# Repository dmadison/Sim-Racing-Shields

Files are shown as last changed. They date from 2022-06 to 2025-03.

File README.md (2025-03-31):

# Sim Racing Shields for Arduino

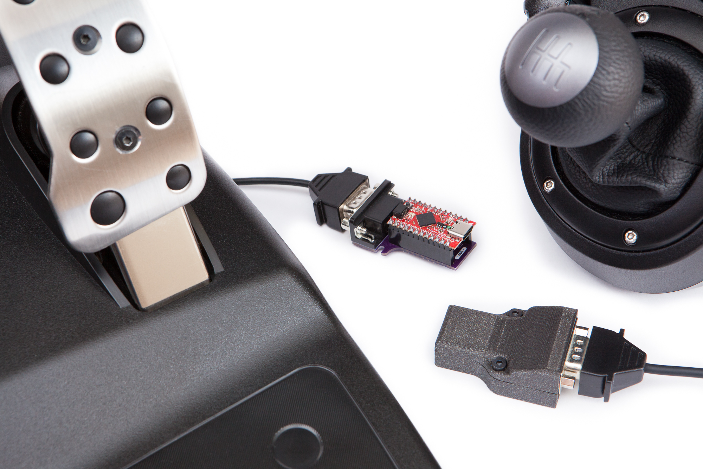
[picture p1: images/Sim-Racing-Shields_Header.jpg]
Sim Racing Shields Header


This repo contains add-on circuit boards ("shields") for connecting Arduino development boards to sim racing equipment. These shields are meant to be used in conjunction with the [Sim Racing Library for Arduino](https://github.com/dmadison/Sim-Racing-Arduino). These shields can be used to create inexpensive, standalone USB HID adapters for use with racing games and simulators.

Both of these shields are designed to be used with a [SparkFun Pro Micro, 5V (32U4)](https://github.com/sparkfun/Pro_Micro). You can use either genuine SparkFun boards or 3rd party clones. The [SparkFun Qwiic Pro Micro with a USB-C port (DEV-15795)](https://www.sparkfun.com/products/15795) is recommended. The SparkFun Pro Micro RP2040 is theoretically compatible but has not been tested. Note that the Tag-Connect programming header is not compatible with the RP2040.

The shields can be assembled with either 0.1″ female headers for prototyping or 0.1″ male headers for a permanent connection. Only assembled boards with male headers will be able to fit inside the 3D printed case.

For more information, [see the article on PartsNotIncluded.com](https://www.partsnotincluded.com/sim-racing-shields-for-arduino/).

## Logitech Shifter Shield for Pro Micro

The [Logitech Shifter Shield](pcbs/Logitech_Shifter_Shield_Pro_Micro) is designed to interface with all available Logitech shifters using a single DB-9 male connector:
* [Logitech Driving Force shifter (G923 / G920 / G29)](https://www.logitechg.com/en-us/products/driving/driving-force-shifter.html)
* [Logitech G27 shifter](https://en.wikipedia.org/wiki/Logitech_G27)
* [Logitech G25 shifter](https://en.wikipedia.org/wiki/Logitech_G25)

This repo includes firmware ([LogitechShifterShield](firmware/LogitechShifterShield/LogitechShifterShield.ino)) which works out of the box as a USB HID adapter for all three shifter types.

You can also write your own firmware using the [Sim Racing Library for Arduino](https://github.com/dmadison/Sim-Racing-Arduino). Use the `SimRacing::CreateShieldObject()` template function for easy setup with the shifter shield:

```cpp
LogitechShifterG29 shifter = SimRacing::CreateShieldObject<SimRacing::LogitechShifterG29, 2>();
LogitechShifterG27 shifter = SimRacing::CreateShieldObject<SimRacing::LogitechShifterG27, 2>();
LogitechShifterG25 shifter = SimRacing::CreateShieldObject<SimRacing::LogitechShifterG25, 2>();
```

## Logitech Pedal Shield for Pro Micro

The [Logitech Pedal Shield](pcbs/Logitech_Pedal_Shield_Pro_Micro) is designed to interface with the Logitech three pedal attachment, included with the Logitech G923 “TRUEFORCE”, G29/G920 “Driving Force”, and G27/G25 wheels, via a single DB-9 female connector.

This repo includes firmware ([LogitechPedalShield](firmware/LogitechPedalShield/LogitechPedalShield.ino)) which works out of the box as a USB HID adapter for the pedals.

You can also write your own firmware using the [Sim Racing Library for Arduino](https://github.com/dmadison/Sim-Racing-Arduino). Use the `SimRacing::CreateShieldObject()` template function for easy setup with the pedals shield:

```cpp
LogitechPedals pedals = SimRacing::CreateShieldObject<SimRacing::LogitechPedals, 2>();
```

## Firmware

The shields are designed to be used with the [Sim Racing Library for Arduino](https://github.com/dmadison/Sim-Racing-Arduino). You can use any included example for your specific hardware, or write your own using the data the library provides.

Both shields use the SparkFun Pro Micro (32U4), and firmware should be compiled using the "SparkFun Pro Micro" board in the Arduino IDE. You can find the compilation files and installation instructions for the Pro Micro [here](https://github.com/sparkfun/Arduino_Boards). You do not need to install the SparkFun boards package if you are using the custom boards package below.

### Custom Boards Installation

To install the custom boards package, start up the Arduino IDE and open the preferences window (**File > Preferences**). Copy and paste this URL for the package index into the "Additional Boards Manager URLs" field:

```
https://github.com/dmadison/Sim-Racing-Shields/raw/master/arduino-boards/boards-manager/package_simracing_index.json
```

In the menu, navigate to **Tools > Board > Boards Manager** and open up the boards manager. Search for "Sim Racing" and then install the "Sim Racing AVR Boards" package. After the package is installed you should be able to select the "SparkFun Pro Micro (for Sim Racing)" board.

### Custom Boards Configuration

The custom boards package adds two new options to the boards menu:

* USB Identity
* Serial Port

The first option, 'USB Identity', changes the USB PID and USB description for the board. Firmware compiled with the 'Shifter' option will present as "Sim Racing Shifter" with a PID of 0x9101, while firmware compiled with the 'Pedals' option will present as "Sim Racing Pedals" with a PID of 0x9102.

The second option, 'Serial Port', allows you to disable the USB CDC serial port. This improves compatibility with some systems and prevents accidentally reprogramming the board. Note that if you remove the USB CDC serial port the board will no longer automatically reset to the bootloader during programming. You will have to reset the board yourself or use an external programmer.

## Case

[A 3D printed case design](cad) is available to protect the assembled shield and microcontroller. Both shields share the same general footprint and the same case design. When assembled, the case should hold the microcontroller and shield securely without any play.

The case is printed in two parts, and assembled using two M3-10 bolts and two M3 nuts. The recommended print orientation is as-is. Note that the top half of the case is a little tricky to print, and must be printed using bed supports.

## Building Your Own

If you'd like to make these yourself, you can find the [Gerber files](https://en.wikipedia.org/wiki/Gerber_format) and [Bill of Materials (BOM)](https://en.wikipedia.org/wiki/Bill_of_materials) in [the latest release](https://github.com/dmadison/Sim-Racing-Shields/releases/latest).

## License

The files in this repository are licensed under the terms of the [GNU General Public License (GPL)](https://www.gnu.org/licenses/gpl-3.0.html), either version 3 of the License, or (at your option) any later version. See the [LICENSE](LICENSE) file for more information.

Included images are licensed under the [CC BY-NC-ND 4.0 license](https://creativecommons.org/licenses/by-nc-nd/4.0/). Attribution should be to Dave Madison ([@dmadison](https://github.com/dmadison)).

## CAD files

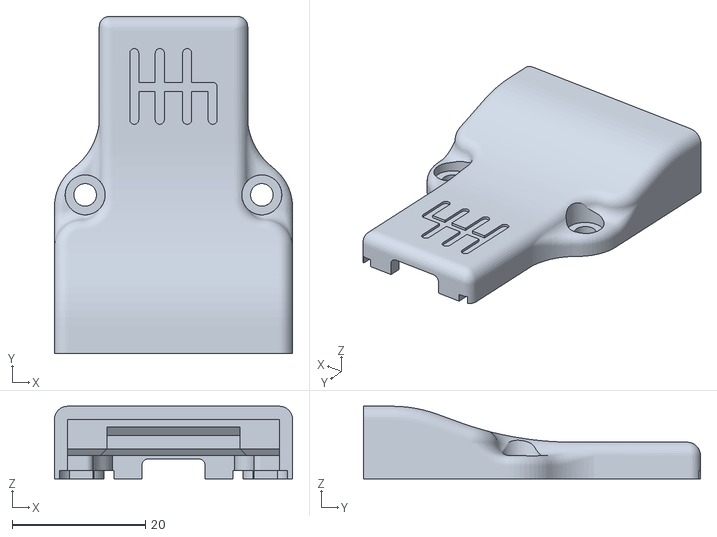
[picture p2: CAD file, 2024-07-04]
cad/Logitech Sim Racing Adapter Case - Top (Shifter).stl
35.7 x 50.6 x 10.9

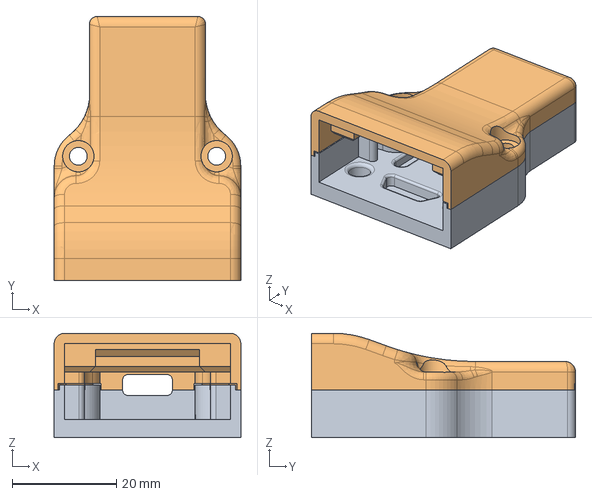
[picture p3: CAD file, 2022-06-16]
cad/Logitech Sim Racing Adapter Case.step
35.7 x 50.6 x 20.0 mm

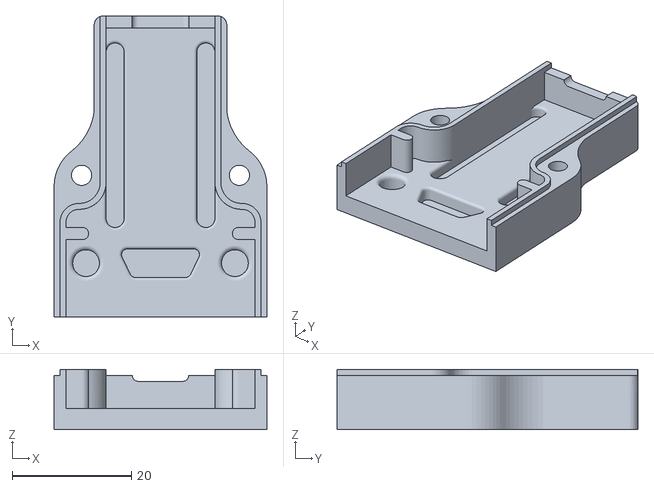
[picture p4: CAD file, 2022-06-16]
cad/Logitech Sim Racing Adapter Case - Bottom.stl
35.7 x 50.6 x 10.1

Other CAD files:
cad/Logitech Sim Racing Adapter Case - Top (Pedals).stl
cad/Logitech Sim Racing Adapter Case - Top.stl
cad/Logitech Sim Racing Adapter Case.f3d

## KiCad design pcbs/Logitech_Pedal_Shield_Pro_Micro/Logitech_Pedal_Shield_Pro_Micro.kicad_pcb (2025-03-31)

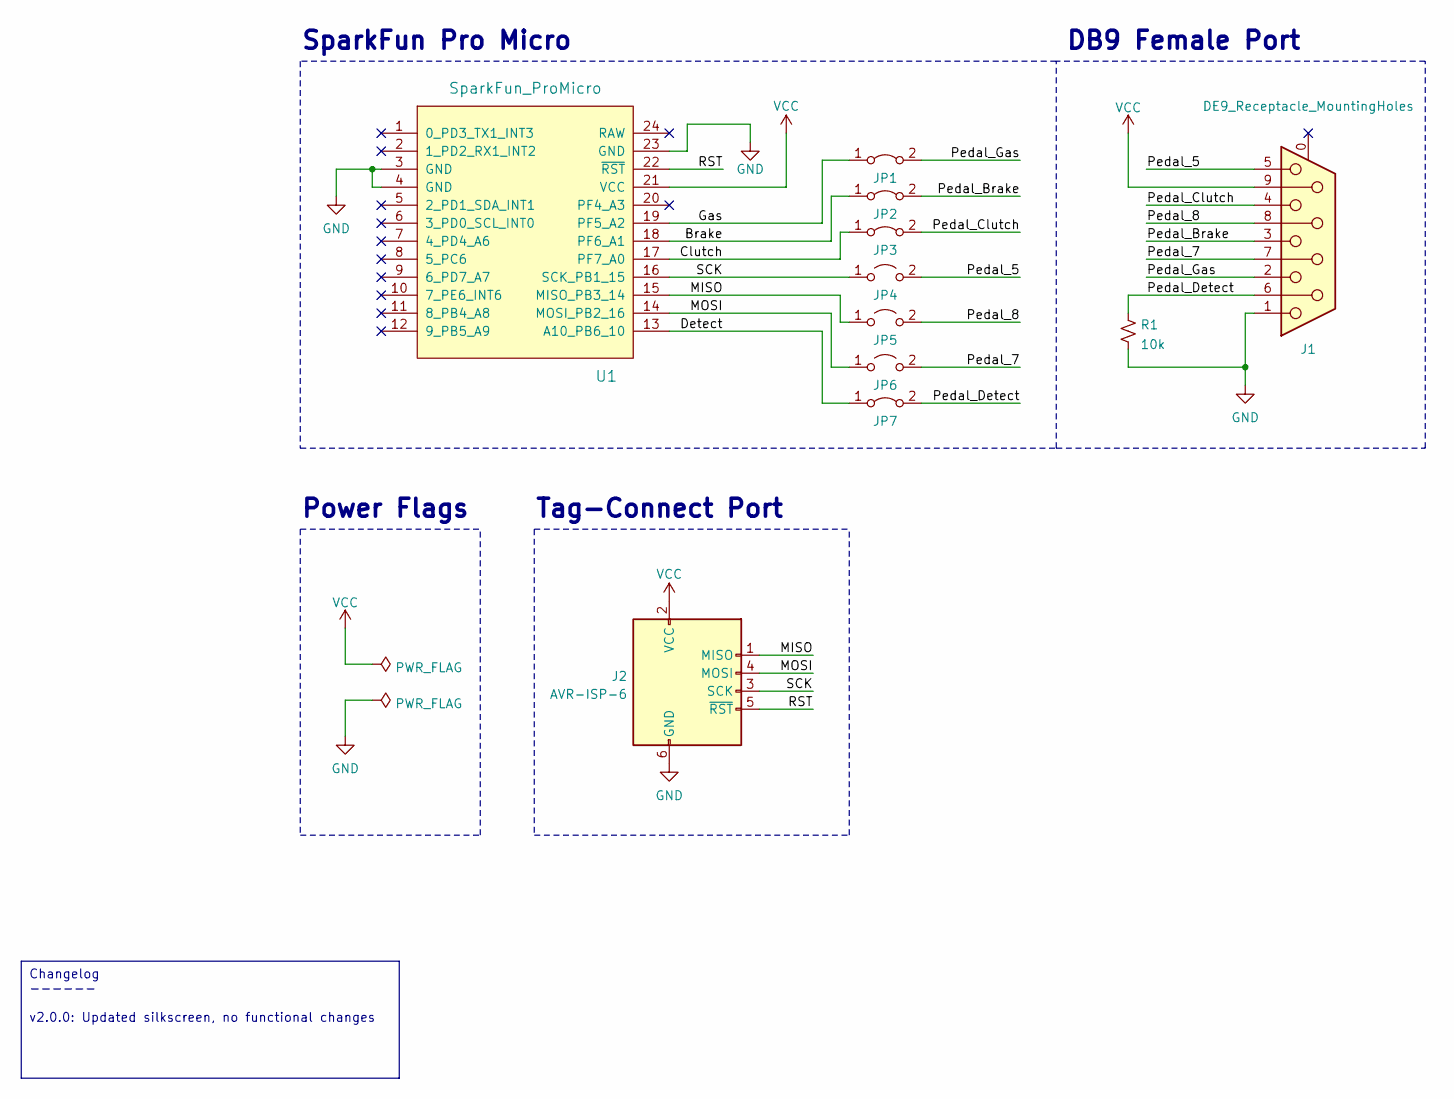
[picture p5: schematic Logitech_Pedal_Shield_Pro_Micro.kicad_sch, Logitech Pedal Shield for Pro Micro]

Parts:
J1: DE9_Receptacle_MountingHoles; DSUB-9_Female_Horizontal_P2.77x2.84mm_EdgePinOffset7.70mm_H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; Part Number A-DF 09 A/KG-T2S; DigiKey Part Number AE10921-ND
J2: AVR-ISP-6; Tag-Connect_TC2030-IDC-NL_2x03_P1.27mm_Vertical
JP1: Gas_Jumper; SolderJumper-2_P1.3mm_Bridged_RoundedPad1.0x1.5mm_Unmasked
JP2: Brake_Jumper; SolderJumper-2_P1.3mm_Bridged_RoundedPad1.0x1.5mm_Unmasked
JP3: Clutch_Jumper; SolderJumper-2_P1.3mm_Bridged_RoundedPad1.0x1.5mm_Unmasked
JP4, JP5, JP6: Jumper_2_Open; SolderJumper-2_P1.3mm_Open_RoundedPad1.0x1.5mm
JP7: Detect_Jumper; SolderJumper-2_P1.3mm_Bridged_RoundedPad1.0x1.5mm_Unmasked
R1: 10k; R_0805_2012Metric; Part Number RC0805FR-0710KP; DigiKey Part Number YAG1319CT-ND
U1: SparkFun_ProMicro; Sparkfun_ProMicro; Part Number DEV-15795; DigiKey Part Number 1568-DEV-15795-ND

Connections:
/Brake: JP2.1 (A), U1.18 (PF6_A1)
/Clutch: JP3.1 (A), U1.17 (PF7_A0)
/Detect: JP7.1 (A), U1.13 (A10_PB6_10)
/Gas: JP1.1 (A), U1.19 (PF5_A2)
/MISO: J2.1 (MISO), JP5.1 (A), U1.15 (MISO_PB3_14)
/MOSI: J2.4 (MOSI), JP6.1 (A), U1.14 (MOSI_PB2_16)
/Pedal_5: J1.5, JP4.2 (B)
/Pedal_7: J1.7, JP6.2 (B)
/Pedal_8: J1.8, JP5.2 (B)
/Pedal_Brake: J1.3, JP2.2 (B)
/Pedal_Clutch: J1.4, JP3.2 (B)
/Pedal_Detect: J1.6, JP7.2 (B), R1.2
/Pedal_Gas: J1.2, JP1.2 (B)
/RST: J2.5 (~RST), U1.22 (~RST)
/SCK: J2.3 (SCK), JP4.1 (A), U1.16 (SCK_PB1_15)
GND: J1.1, J2.6 (GND), R1.1, U1.3 (GND), U1.4 (GND), U1.23 (GND)
VCC: J1.9, J2.2 (VCC), U1.21 (VCC)

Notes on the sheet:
Changelog ------ v2.0.0: Updated silkscreen, no functional changes
Tag-Connect Port
Power Flags
DB9 Female Port
SparkFun Pro Micro

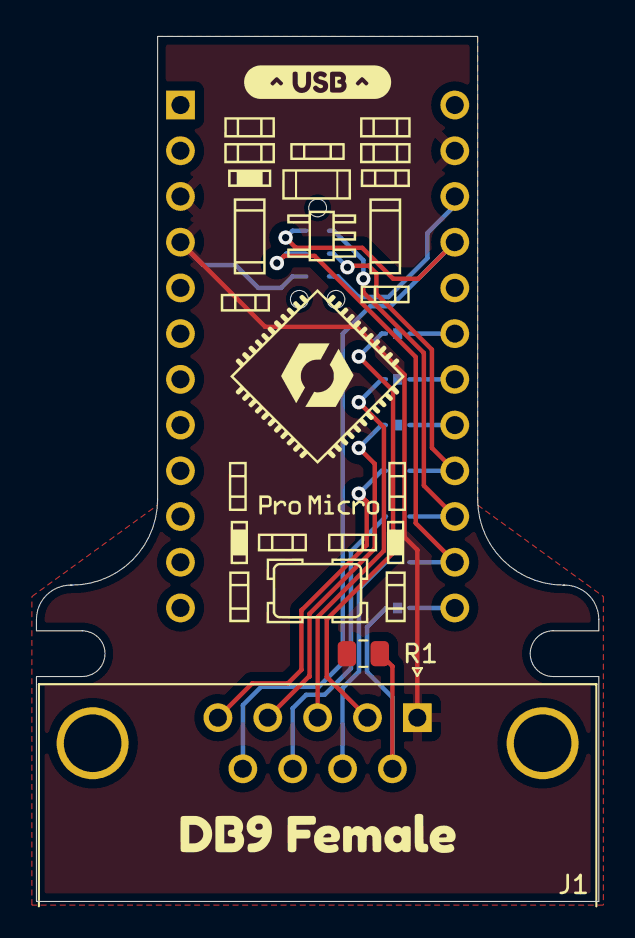
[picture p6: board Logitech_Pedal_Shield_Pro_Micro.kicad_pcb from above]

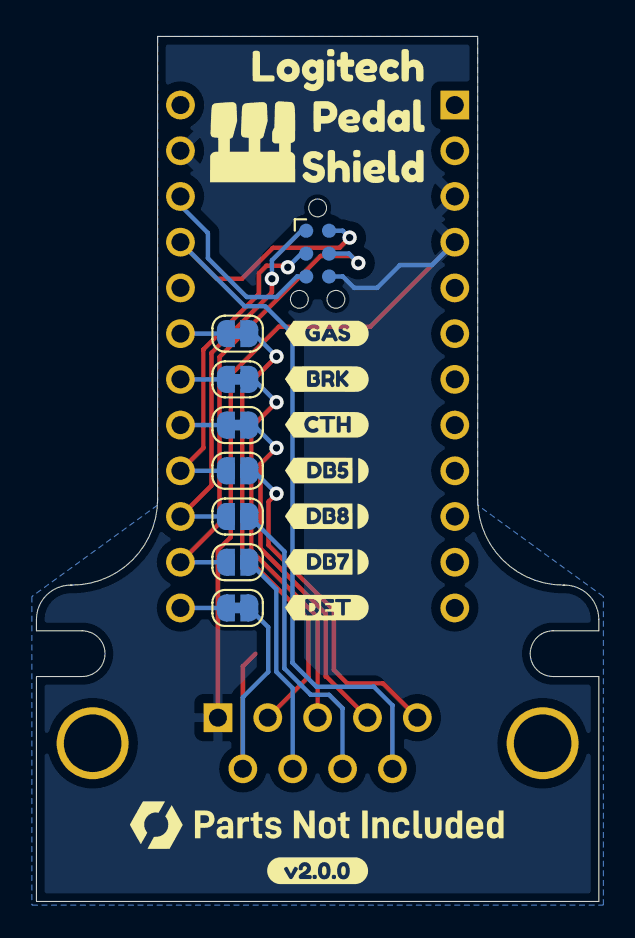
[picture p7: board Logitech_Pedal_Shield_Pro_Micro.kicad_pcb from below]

Board: 2 copper layers, 31.2 x 48.1 mm, 12 parts (8 on the bottom side), 17 nets.

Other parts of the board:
kibuzzard-61EDBB73: G***; kibuzzard-61EDBB73

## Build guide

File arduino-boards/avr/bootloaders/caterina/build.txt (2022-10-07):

make clean
make PID=0x9209 F_CPU=16000000
copy Caterina.hex Caterina-wiflyin.hex
make clean
make PID=0x9207 F_CPU=8000000
copy Caterina.hex Caterina-lilypadusb.hex
make clean
make PID=0x9205 F_CPU=16000000
copy Caterina.hex Caterina-promicro16.hex
make clean
make PID=0x9203 F_CPU=8000000
copy Caterina.hex Caterina-promicro8.hex 
make clean
make PID=0x2B74 F_CPU=16000000
copy Caterina.hex Caterina-makey.hex
make clean
make PID=0xF100 F_CPU=8000000
copy Caterina.hex Caterina-fio.hex
make clean
make PID=0x920B F_CPU=16000000
copy Caterina.hex Caterina-minibench.hex
make clean
make PID=0x0110 F_CPU=8000000
copy Caterina.hex Caterina-lilypadusbplus.hex

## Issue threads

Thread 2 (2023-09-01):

R1 resistor on Logitech_Pedal_Shield_Pro_Micro

lkvapil, 2023-09-01:
Hi!

just wondering why did you add a R1-10k resistor between 5-9pin on the DB9 connector (6-1 in the schematics)
Is there any other purpose of the resistor ?
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

Doing some research, did a teardown of the pedals and G29 base and seems, that on the DB9 connector pins 6 and 9 does need 3V3 voltage.
Also on the DB9 on the pedals cable are pins 6 and 9 connected..

Thank you

Best regards
Lukas

dmadison, 2023-09-01:
Hi Lukas! That's a great question.

You can see the results of my own breakdown of the pinout [in the library documentation](https://dmadison.github.io/Sim-Racing-Arduino/docs/logitech_pedals.html).

As you've discovered, pins 6 and 9 and connected internally in the pedal connector. The shield provides power on pin 9, which means pin 6 also gets powered whenever the pedals are connected. This allows pin 6 to be used as a detection pin, where the resistor (R1) acts as a pull-down. When the pedals are disconnected the pin is low (through the resistor), when the pedals are connected the pin is high (connected to VCC through pin 9).

If you don't care about the detection feature you can omit the resistor and the detection pin in the object constructor. The microcontroller will just read/send junk values when the pedals are disconnected.

>on the DB9 connector pins 6 and 9 does need 3V3 voltage.

On my pedals at least the only connections inside the pedals are to the pedal potentiometers themselves, which can use any high level voltage below the limit of the potentiometer. 5V works fine.

>between 5-9pin on the DB9 connector (6-1 in the schematics)

Careful that you're using the correct DB9 connector! The footprint is flipped depending on the gender. The connector pinout on the shield should match the schematic 1:1.

dmadison, 2023-09-04:
I haven't heard back from you so I'm considering this solved. Feel free to reopen if you have more questions.

Closed 2023-09-04.

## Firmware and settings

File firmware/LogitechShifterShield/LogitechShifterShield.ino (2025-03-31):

/*
 *  Project     Sim Racing Shields for Arduino
 *  @author     David Madison
 *  @link       github.com/dmadison/Sim-Racing-Shields
 *  @license    GPLv3 - Copyright (c) 2025 David Madison
 *
 *  This file is part of the Sim Racing Shields for Arduino project.
 *
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
 *  You should have received a copy of the GNU General Public License along with
 *  this program.  If not, see <http://www.gnu.org/licenses/>.
 */

 /**
 * @details Reads from a Logitech shifter connected to the shifter shield
 *          and sends its data as a USB joystick.
 * @example LogitechShifterShield.ino
 */

 // This firmware requires the Arduino Joystick Library
 // Download Here: https://github.com/MHeironimus/ArduinoJoystickLibrary/releases/latest

#include <SimRacing.h>
#include <Joystick.h>

// Option to compile with support for the Logitech Driving Force shifter
// 
// The Driving Force shifter is included with the G923, G920, and G29 wheels
// Includes: 7 gears
#define USE_SHIFTER_DRIVING_FORCE

// Option to compile with support for the Logitech G27 shifter
// 
// Includes: 7 gears, 8 buttons, hat switch
#define USE_SHIFTER_G27

// Option to compile with support for the Logitech G25 shifter
// 
// Includes: 7 gears, 8 buttons, hat switch, 2 sequential shift buttons
#define USE_SHIFTER_G25

// Option to send the analog axis data as joystick axes.
// 
// NOT needed for any standard games, but can be useful for custom
// controller purposes
//#define SEND_ANALOG_AXES

// Option to always send USB data, regardless of whether it has changed
// 
// This shouldn't be necessary, but if you're having issues with missed
// packets for some reason this could be useful
//#define ALWAYS_SEND_DATA

// Option to disable the USB TX / RX LEDs
// 
// These LEDs are useful to indicate that the device is working as intended,
// but can be disabled to make the device more stealthy
#define DISABLE_USB_LEDS

// -----------------------------------

#if !defined(USE_SHIFTER_DRIVING_FORCE) && !defined(USE_SHIFTER_G27) && !defined(USE_SHIFTER_G25)
#error "You must define at least 1 shifter type"
#endif


// Gear definitions. Change this array to change the gear to USB
// button assignments
const int Gears[] = { 1, 2, 3, 4, 5, 6, -1 };
const int NumGears = sizeof(Gears) / sizeof(Gears[0]);

// Button definitions. Change this array to change the shifter button
// to USB button assignments
using ShifterButton = SimRacing::LogitechShifterG25::Button;
const ShifterButton Buttons[] = {
	ShifterButton::BUTTON_SOUTH,
	ShifterButton::BUTTON_EAST,
	ShifterButton::BUTTON_WEST,
	ShifterButton::BUTTON_NORTH,
	ShifterButton::BUTTON_1,
	ShifterButton::BUTTON_2,
	ShifterButton::BUTTON_3,
	ShifterButton::BUTTON_4,
};
#if defined(USE_SHIFTER_G27) || defined(USE_SHIFTER_G25)
const int NumButtons = sizeof(Buttons) / sizeof(Buttons[0]);
#else
const int NumButtons = 0;
#endif


#if defined(USE_SHIFTER_G25)
// 7 gears, 8 buttons, 2 sequential inputs
const int NumJoystickButtons = NumGears + NumButtons + 2;
const int NumHatSwitches = 1;

#elif defined(USE_SHIFTER_G27)
// 7 gears, 8 buttons
const int NumJoystickButtons = NumGears + NumButtons;
const int NumHatSwitches = 1;

#elif defined(USE_SHIFTER_DRIVING_FORCE)
// 7 gears, no buttons
const int NumJoystickButtons = NumGears;
const int NumHatSwitches = 0;

#else
// nothing D:
// (fixes compilation issues so that the preprocessor #error shows first)
const int NumJoystickButtons = 0;
const int NumHatSwitches = 0;

#endif

#if defined(SEND_ANALOG_AXES)
const bool SendAnalogAxes = true;
#else
const bool SendAnalogAxes = false;
#endif


Joystick_ Joystick(
	JOYSTICK_DEFAULT_REPORT_ID,      // default report (no additional pages)
	JOYSTICK_TYPE_JOYSTICK,          // so that this shows up in Windows joystick manager
	NumJoystickButtons,              // number of buttons
	NumHatSwitches,                  // number of hat switches
	SendAnalogAxes, SendAnalogAxes,  // include X and Y axes for analog output, if enabled
	false, false, false, false, false, false, false, false, false);  // no other axes

const int ADC_Max = 1023;  // 10-bit on AVR

struct JoystickData {
	int gear = 0;

	#if defined(USE_SHIFTER_G27) || defined(USE_SHIFTER_G25)
	int      dpadAngle = -1;
	uint32_t buttons   = 0x00;
	#endif

	#if defined(USE_SHIFTER_G25)
	bool     seqUp     = 0;
	bool     seqDown   = 0;
	#endif

	#if defined(SEND_ANALOG_AXES)
	int x = ADC_Max / 2;
	int y = ADC_Max / 2;
	#endif

	bool operator == (const JoystickData& rhs) const {
		if (this->gear != rhs.gear) return false;

		#if defined(USE_SHIFTER_G27) || defined(USE_SHIFTER_G25)
		if (this->dpadAngle != rhs.dpadAngle) return false;
		if (this->buttons   != rhs.buttons)   return false;
		#endif

		#if defined(USE_SHIFTER_G25)
		if (this->seqUp     != rhs.seqUp)     return false;
		if (this->seqDown   != rhs.seqDown)   return false;
		#endif

		#if defined(SEND_ANALOG_AXES)
		if (this->x != rhs.x) return false;
		if (this->y != rhs.y) return false;
		#endif

		return true;
	}
};


// forward-declared functions for non-Arduino environments
void parseShifter(SimRacing::LogitechShifter& shifter,    JoystickData& data);
void parseShifter(SimRacing::LogitechShifterG27& shifter, JoystickData& data);
void parseShifter(SimRacing::LogitechShifterG25& shifter, JoystickData& data);

void updateUSB(const JoystickData& data);


/**
* Parse the joystick data from the Logitech Driving Force shifter
*
* @param shifter The Logitech shifter to read from
* @param data Reference to a joystick data struct to store the data into
*/
void parseShifter(SimRacing::LogitechShifter& shifter, JoystickData& data) {
	shifter.update();

	if (shifter.isConnected()) {
		data.gear = shifter.getGear();

		#if defined(SEND_ANALOG_AXES)
		data.x = shifter.getPosition(SimRacing::X, 0, ADC_Max);
		data.y = shifter.getPosition(SimRacing::Y, 0, ADC_Max);
		#endif
	}
}


/**
* Parse the joystick data from the Logitech G27 shifter
*
* @param shifter The Logitech G27 shifter to read from
* @param data Reference to a joystick data struct to store the data into
*/
void parseShifter(SimRacing::LogitechShifterG27& shifter, JoystickData& data) {
	shifter.update();

	if (shifter.isConnected()) {
		data.gear = shifter.getGear();

		#if defined(USE_SHIFTER_G27)
		for (int i = 0; i < NumButtons; ++i) {
			const bool state = shifter.getButton(Buttons[i]);
			data.buttons |= state << i;
		}

		data.dpadAngle = shifter.getDpadAngle();
		#endif

		#if defined(SEND_ANALOG_AXES)
		data.x = shifter.getPosition(SimRacing::X, 0, ADC_Max);
		data.y = shifter.getPosition(SimRacing::Y, 0, ADC_Max);
		#endif
	}
}


/**
* Parse the joystick data from the Logitech G25 shifter
*
* @param shifter The Logitech G25 shifter to read from
* @param data Reference to a joystick data struct to store the data into
*/
void parseShifter(SimRacing::LogitechShifterG25& shifter, JoystickData& data) {
	shifter.update();

	if (shifter.isConnected()) {
		data.gear = shifter.getGear();

		#if defined(USE_SHIFTER_G25)
		for (int i = 0; i < NumButtons; ++i) {
			const bool state = shifter.getButton(Buttons[i]);
			data.buttons |= state << i;
		}

		data.dpadAngle = shifter.getDpadAngle();

		data.seqUp   = shifter.getShiftUp();
		data.seqDown = shifter.getShiftDown();
		#endif

		#if defined(SEND_ANALOG_AXES)
		data.x = shifter.getPosition(SimRacing::X, 0, ADC_Max);
		data.y = shifter.getPosition(SimRacing::Y, 0, ADC_Max);
		#endif
	}
}


/**
* Read the joystick data and set the USB output
* 
* @param data Reference to the joystick data struct to read from
*/
void updateUSB(const JoystickData& data) {
	static JoystickData previousData;

	#if !defined(ALWAYS_SEND_DATA)
	// if data hasn't changed, don't send an update
	if (data == previousData) return;
	#endif

	uint8_t currentButton = 0;

	// set the buttons corresponding to the gears
	for (int i = 0; i < NumGears; ++i) {
		if (data.gear == Gears[i]) {
			Joystick.pressButton(currentButton);
		}
		else {
			Joystick.releaseButton(currentButton);
		}

		currentButton++;
	}

	#if defined(USE_SHIFTER_G27) || defined(USE_SHIFTER_G25)
	// set the hat switch (directional pad)
	Joystick.setHatSwitch(0, data.dpadAngle);

	// set the buttons from the bitfield
	for (int i = 0; i < NumButtons; ++i) {
		const bool state = data.buttons & (1 << i);
		Joystick.setButton(currentButton, state);
		currentButton++;
	}
	#endif

	#if defined(USE_SHIFTER_G25)
	// set the sequential buttons
	Joystick.setButton(currentButton++, data.seqUp);
	Joystick.setButton(currentButton++, data.seqDown);
	#endif

	#if defined(SEND_ANALOG_AXES)
	// set the analog axes
	Joystick.setXAxis(data.x);
	Joystick.setYAxis(data.y);
	#endif

	// send the USB update
	Joystick.sendState();

	previousData = data;
}

void setup() {
	#if defined(DISABLE_USB_LEDS)
	pinMode(30, INPUT);  // TX LED
	pinMode(17, INPUT);  // RX LED
	#endif

	Joystick.begin(false);  // 'false' to disable auto-send
	Joystick.setXAxisRange(0, ADC_Max);
	Joystick.setYAxisRange(ADC_Max, 0);  // invert axis so 'up' is up

	// Define the Driving Force (G923 / G920 / G29) instance
	// Since the G27 uses the same detection pin, only create the simpler Driving
	// Force instance if we're not supporting the G27 as well
	#if defined(USE_SHIFTER_DRIVING_FORCE) && !defined(USE_SHIFTER_G27)
		SimRacing::LogitechShifter df = SimRacing::CreateShieldObject<SimRacing::LogitechShifter, 2>();
		// if you have one, your calibration line should go here
		df.begin();
	#endif  // USE_SHIFTER_DRIVING_FORCE

	// Define the G27 instance
	#if defined(USE_SHIFTER_G27)
		SimRacing::LogitechShifterG27 g27 = SimRacing::CreateShieldObject<SimRacing::LogitechShifterG27, 2>();
		// if you have one, your calibration line should go here
		g27.begin();
	#endif  // USE_SHIFTER_G27

	// Define the G25 instance
	#if defined(USE_SHIFTER_G25)
		SimRacing::LogitechShifterG25 g25 = SimRacing::CreateShieldObject<SimRacing::LogitechShifterG25, 2>();
		// if you have one, your calibration line should go here
		g25.begin();
	#endif

	while (true) {
		JoystickData data;

		// Logitech Driving Force shifter processing
		#if defined(USE_SHIFTER_DRIVING_FORCE) && !defined(USE_SHIFTER_G27)
		parseShifter(df, data);
		#endif

		// Logitech G27 shifter processing
		#if defined(USE_SHIFTER_G27)
		parseShifter(g27, data);
		#endif

		// Logitech G25 shifter processing
		#if defined(USE_SHIFTER_G25)
		parseShifter(g25, data);
		#endif

		updateUSB(data);
	}
}

void loop() {}  // intentionally empty

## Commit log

2022-06-16 Created SparkFun boards files
    These are from the AVR portion of the SparkFun Arduino_Boards repo (https://github.com/sparkfun/Arduino_Boards), using the latest commit (faf2160a).
2022-06-16 Remove Unnecessary SparkFun Boards Files
    Since we're only focused on the Pro Micro, this removes all of the unnecessary files including the other bootloaders, libraries, and headers for the other variants.
2022-06-16 Remove non Pro Micro board definitions
2022-06-16 Modified Arduino boards for Sim Racing
    Using the custom USB VID/PID values from pid.codes
2022-06-17 Add boards manager package and index
    Generated using Adafruit's Arduino board package tool (BPT): https://github.com/adafruit/arduino-board-index/blob/gh-pages/bpt.py
2022-06-17 Add custom boards section to README
2022-06-20 Add 'for Arduino' to README title
    I know, *technically* you can use these outside the Arduino environment, but still.
2024-07-04 Add STLs for engraved top cases (#3)
    These are already a part of the included Fusion 360 file, but suppressed at the end of the feature tree. At the time, adding additional STLs that were identical to the existing "Top" STL in everythin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
    [Logitech Sim Racing Adapter Case - Top (Pedals).stl, Logitech Sim Racing Adapter Case - Top (Shifter).stl]
2025-01-19 KiCad 8 Format Updates (#4)
    * Add KiCad files to gitignore
    * Update PCBs to KiCad8 format (8.0.8)
    * Relink DE-9 connector symbols
    * Update modified schematic symbols
    * Pedals: Fix 'wire off grid' schematic error
    * Set min_copper_edge_clearance
    * Update PCBs from schematic
    This updates the format of the PCB files to be compatible with KiCad 8 There are no intended functional changes.
    [Logitech_Pedal_Shield_Pro_Micro.kicad_pcb, Logitech_Pedal_Shield_Pro_Micro.kicad_sch, Logitech_Shifter_Shield_Pro_Micro.kicad_pcb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]
2025-01-19 Bill of Materials (BOM) (#5)
    Adds Bill of Materials (BOM) information to the KiCad schematic, which can be exported to CSV using the "Generate Bill of Materials" option in the toolbar of the schematic editor.
    These parts are, to the best of my knowledge, the parts I used when assembling these boards two and a half years ago. You do not need to use these exact parts, substitutes may be available that are currently stocked and/or less expensive. The 1% resistors, in particular, do not need to be tight tolerance - that's just what I had on hand.
    [Logitech_Pedal_Shield_Pro_Micro.kicad_sch, Logitech_Shifter_Shield_Pro_Micro.kicad_sch]
2025-01-19 PCB: Fix copper edge clearance
2025-01-23 Add v1 release dates to PCB drawing sheets
    [Logitech_Pedal_Shield_Pro_Micro.kicad_pcb, Logitech_Pedal_Shield_Pro_Micro.kicad_sch, Logitech_Shifter_Shield_Pro_Micro.kicad_pcb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]
2025-01-23 Add KiCad drawing sheet template
    Includes the Parts Not Included logo and the GitHub URL for the repository
2025-03-31 Shifter Shield Version 2 (G25 + G27) (#6)
    * Shifter: Changed all jumpers to NC
    We need all of these pins in order to interface with the Logitech G25 shifter
    * Shifter: Move power to pin 9 (swap 7/9)
    This is an error on the v1 PCB, and the fundamental reason why this PCB doesn't work with the G25 shifter.
    On the Driving Force shifter, pins 7 and 9 are connected together internally in the DE-9 connector. Power applied to one goes to both pins, so one is used to power the shifter and the other is used with a pull-down to act as a detection pin. Since it didn't seem to matter I arbitrarily chose pin 7 as the power input for easier trace routing.
    On the G25 shifter, pins *1* and 9 are connec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
    [Logitech_Shifter_Shield_Pro_Micro.kicad_pcb, Logitech_Shifter_Shield_Pro_Micro.kicad_sch]
2025-03-31 Pedal Shield Version 2 (#7)
    * Pedals: Update PCB version to v2.0.0
    Matching the shifter, just so that the major repo version matches the PCB version to avoid confusion. No functional changes.
    * Pedals: Update footprints for KiCad 8
    Changed the DE-9 and Tag-Connect footprints
    * Pedals: Update fill zones for KiCad 8
    Using the updated fill parameters, with a small keepout zone added for the Tag Connect header
    * Pedals: Add firmware
    * Modify README for pedals v2
    [Logitech_Pedal_Shield_Pro_Micro.kicad_pcb, Logitech_Pedal_Shield_Pro_Micro.kicad_sch]

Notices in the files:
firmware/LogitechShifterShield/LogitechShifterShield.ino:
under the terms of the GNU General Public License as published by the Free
